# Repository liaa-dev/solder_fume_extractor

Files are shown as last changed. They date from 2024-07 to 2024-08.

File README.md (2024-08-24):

# Solder Fume Extractor

A DIY solder fume extractor crafted from a simple USB office fan.

Before:
usb office fan

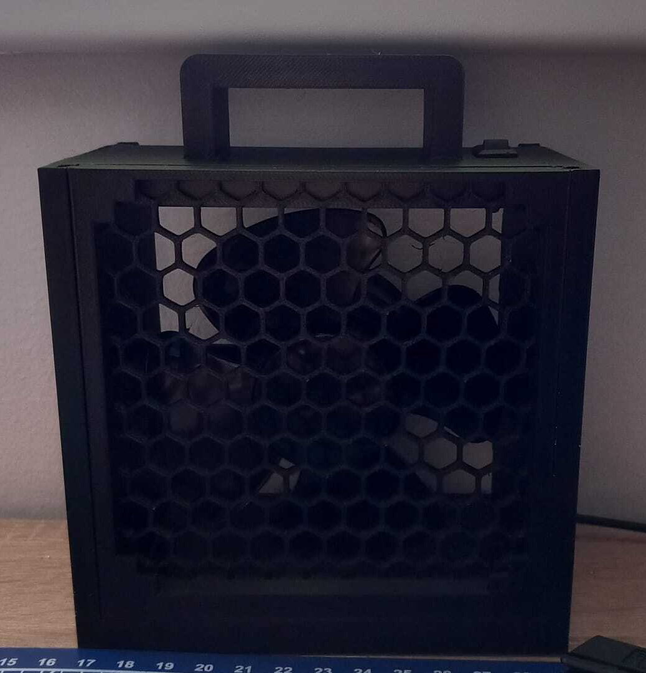
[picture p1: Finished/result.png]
result
After: 

## Description

This repository provides all the necessary files and instructions to build a solder fume extractor using a repurposed USB office fan. The 3D models have been designed in Autodesk Fusion 360 and are optimized for printing on standard 3D printers.

## Requirements

To create your own solder fume extractor, you'll need:

- **3D Printer**: A printer with a minimum bed size of 18x18x18 cm.
- **Filament**: PLA is recommended, but other materials may also be suitable.
- **USB Office Fan**: Ensure the fan has three screws on the back for secure attachment.                   
   [Example link to purchase fan](https://www.amazon.de/CSL-Ventilator-Tischventilator-Schreibtisch-Aus-Schalter/dp/B00CHI1H2S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)       
[Another example link to purchase fan](https://www.allbranded.at/p/USB-Ventilator-schwarz-ohne-Werbeanbringung/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)
- **Charcoal Filter (Front)**: Any filter up to 0.5mm thick.
- **HEPA Filter (Back)**: Any filter up to 0.5mm thick.

## Assembly Instructions

1. Download the files labeled "Filter Back," "Filter Front," and "Fume Extractor Main" from the `/finished` folder.
2. Import these files into your preferred slicer software.
3. Print the components using your 3D printer.

*Note*: Additional files such as screws and nuts are included for potential future enhancements (e.g., solder arms or adjustable arms). These components are optional and not required for the basic fume extractor assembly.

The estimated filament usage is:
- **Filter components**: 140g to 180g per filter (multiply by 2 for both filters).
- **Main part**: Approximately 260g.

## Usage Warning

**Important**: If you intend to print the screws and nuts, apply an XY Compensation of 0.1 to 0.15mm (e.g., in Bambu Slicer). This adjustment is essential to ensure proper fit and functionality of the screws and nuts.

## Contributing

Contributions are welcome! If you enhance or update this project, please use the provided screw and nut files from the `/finished` folder. This will help maintain compatibility with the existing design and avoid measurement issues.

When contributing, ensure that all relevant tests and validations are updated accordingly.

## License

This project is licensed under the MIT License. See the [LICENSE](https://pitt.libguides.com/openlicensing/MIT) file for more details.

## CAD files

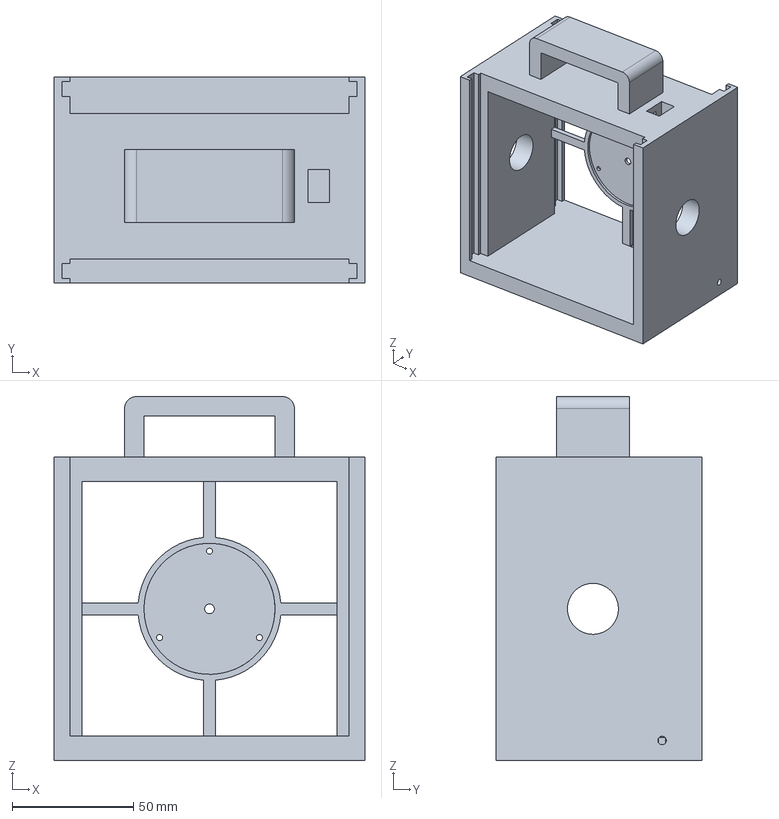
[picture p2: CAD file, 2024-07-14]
Finished/Fume Extractor Main.step
128.0 x 85.0 x 150.0 mm

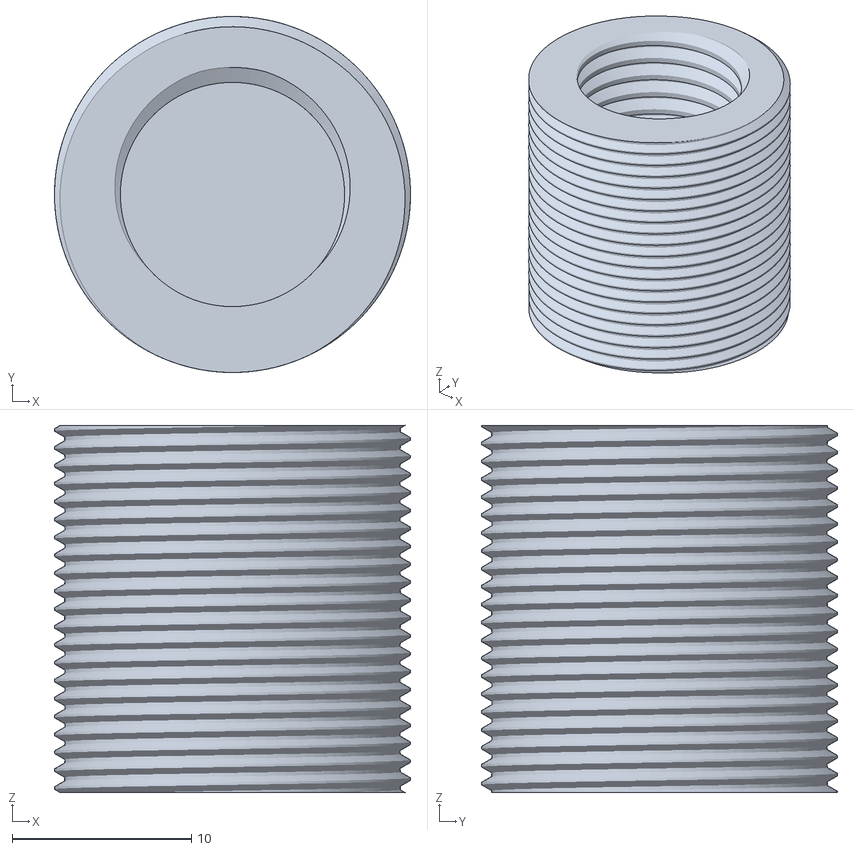
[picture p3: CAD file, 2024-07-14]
Finished/Gewinde.stl
19.9 x 19.9 x 20.5

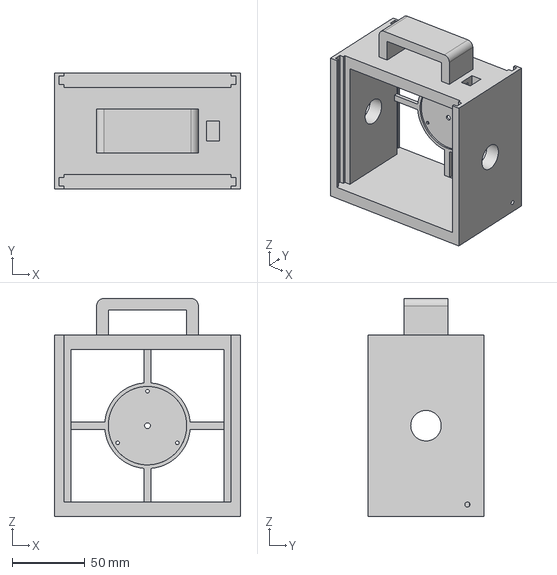
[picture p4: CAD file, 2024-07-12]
session-commits/improved.step
128.0 x 80.0 x 150.0 mm

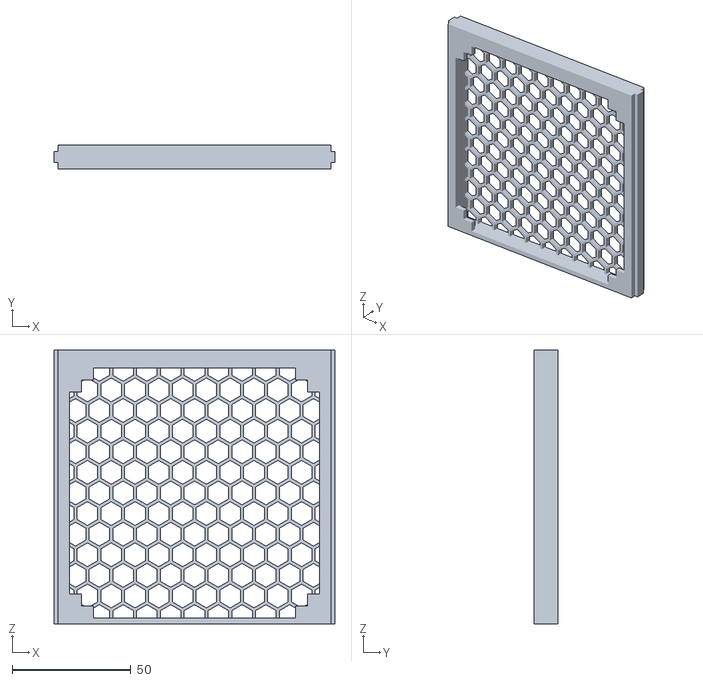
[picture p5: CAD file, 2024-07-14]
Finished/Filter Front.stl
118.1 x 10.0 x 115.0

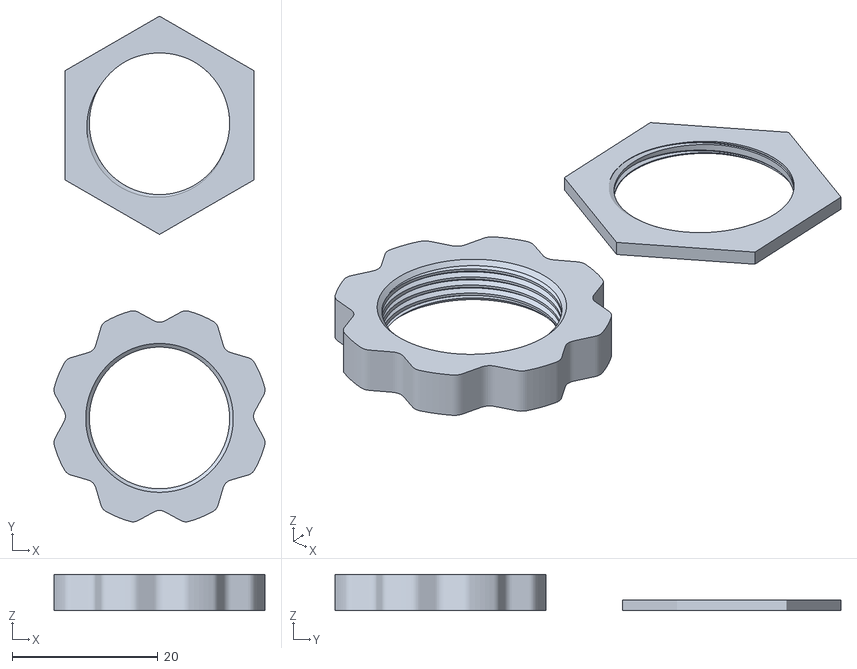
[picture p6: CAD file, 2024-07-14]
Finished/Außen Mutter.stl
29.0 x 69.5 x 5.00

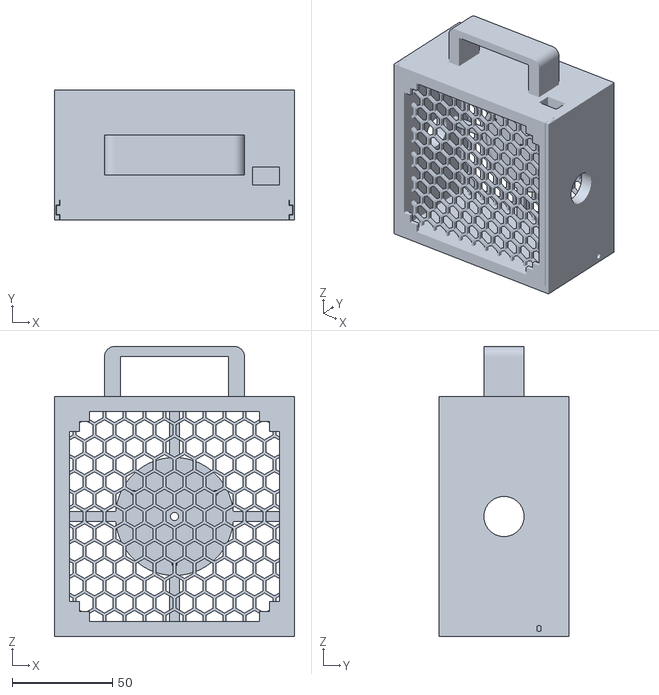
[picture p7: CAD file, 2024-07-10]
session-commits/Solder Fume Extractor v2.stl
120.0 x 65.0 x 145.0

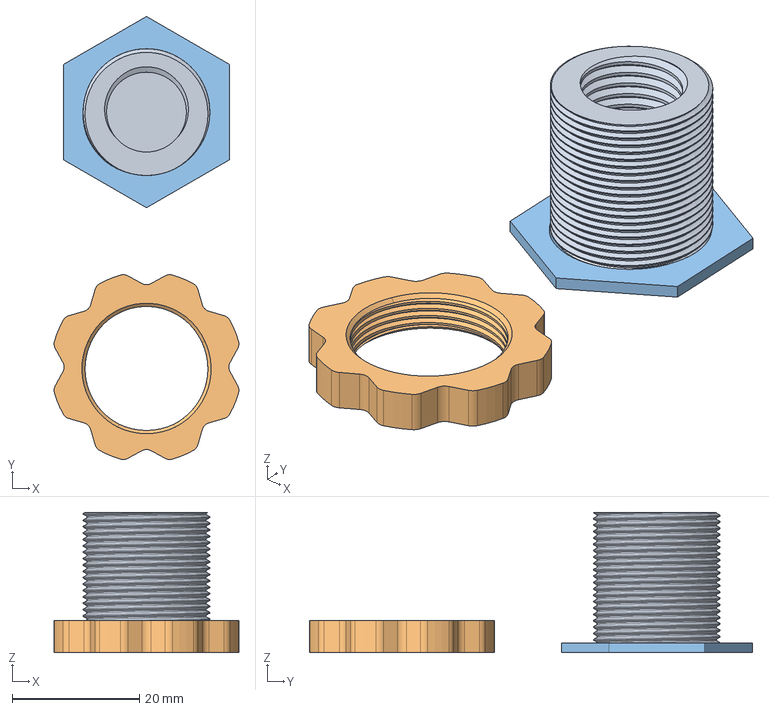
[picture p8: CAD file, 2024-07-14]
Finished/Gewinde & Muttern.step
29.0 x 69.5 x 22.0 mm

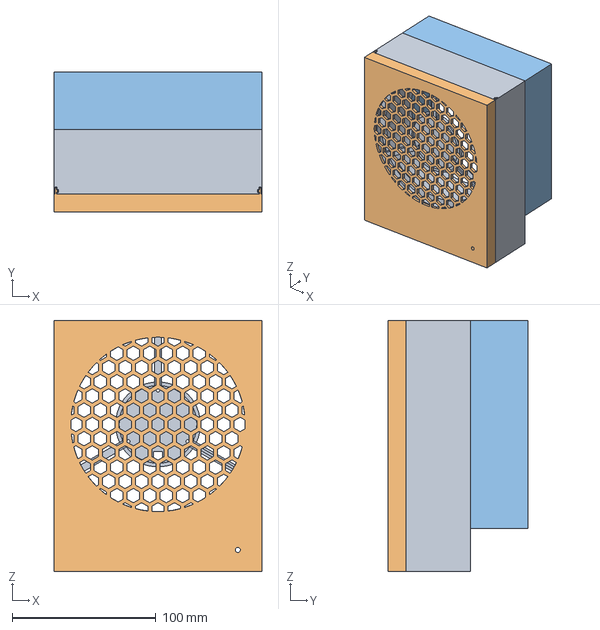
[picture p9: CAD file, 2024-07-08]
session-commits/Solder Fume Extractor v1.step
144.5 x 97.5 x 174.5 mm

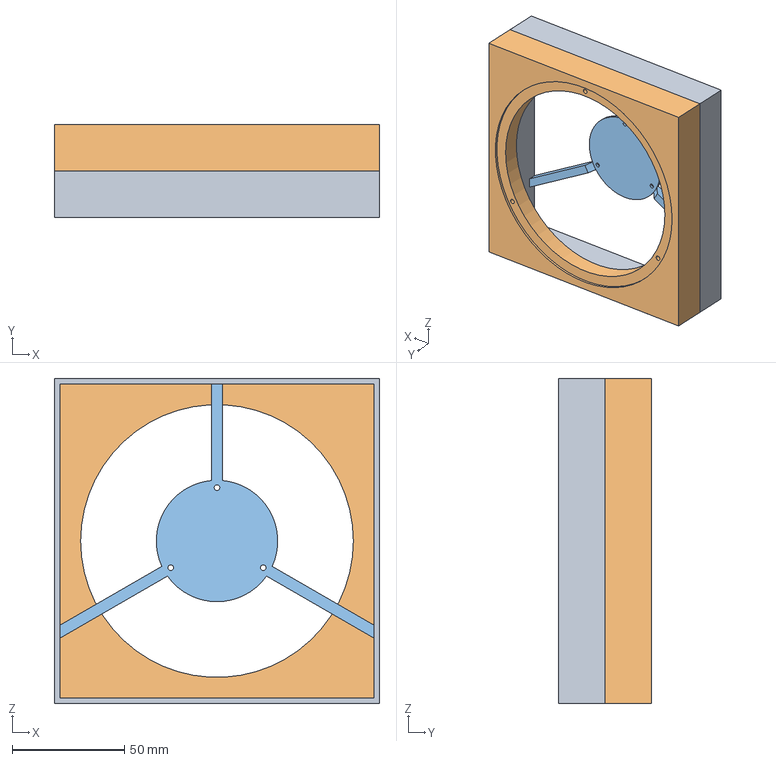
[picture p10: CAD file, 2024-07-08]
session-commits/My Solder Fume Extractor.step
144.5 x 41.5 x 144.5 mm

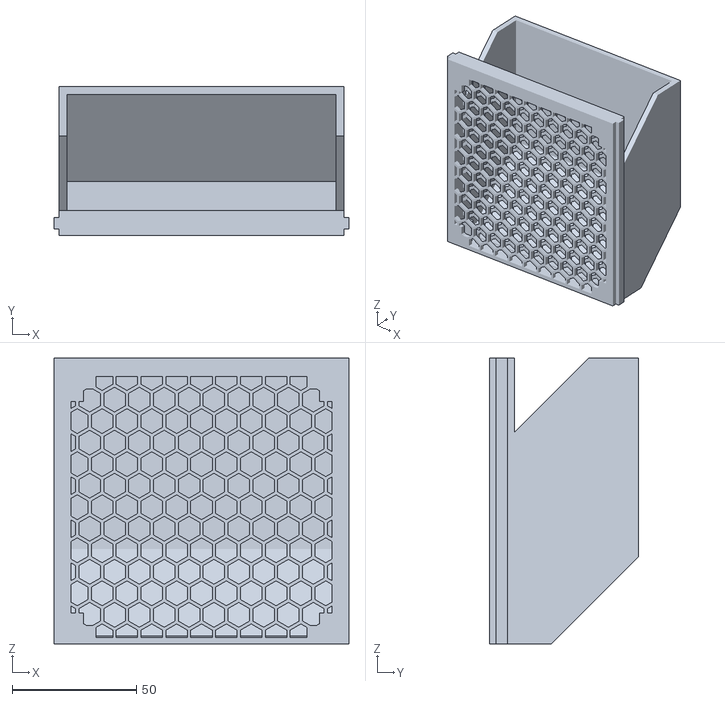
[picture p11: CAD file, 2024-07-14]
Finished/Filter Back.stl
118.7 x 60.0 x 115.0

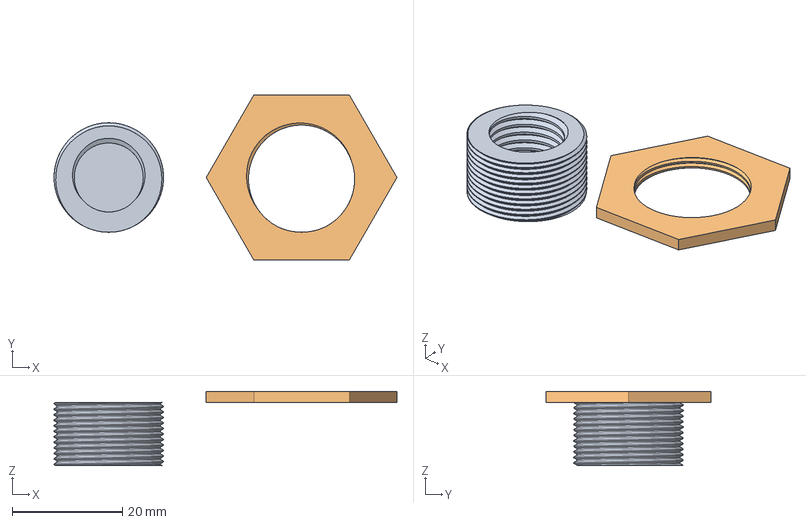
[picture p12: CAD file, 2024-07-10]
session-commits/Armscrew for Solder Fume Extractor v2.step
62.3 x 30.0 x 13.5 mm

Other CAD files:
session-commits/New Solder Fume Extractor.step
Finished/Fume Extractor Main.stl
session-commits/Armscrew for Solder Fume Extractor v2.stl
session-commits/My Solder Fume Extractor.stl
session-commits/New Solder Fume Extractor.stl
session-commits/Solder Fume Extractor v1.stl
session-commits/improved.stl

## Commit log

2024-07-08 not done yet
    [My Solder Fume Extractor.step, My Solder Fume Extractor.stl]
2024-07-08 Finished the v1 of the soldering extractor
    Maybe I will redesign it if I notice something needs to be made better but that's it for v1
    [Solder Fume Extractor v1.step, Solder Fume Extractor v1.stl]
2024-07-10 Redesign filter in back and front
    [New Solder Fume Extractor.step, New Solder Fume Extractor.stl]
2024-07-10 Solder Fume Extractor v2
    Added Soldering arm holder, 2 Filter places (one hepa, other one carbon), made it smaller
    [Solder Fume Extractor v2.step, Solder Fume Extractor v2.stl]
2024-07-10 The Screw and nut for the 2 arm holder holes
    [Armscrew for Solder Fume Extractor v2.step, Armscrew for Solder Fume Extractor v2.stl]
2024-07-12 Improved design of final v2
    Changed following bullet points:
    Need to make the slide in for the filters more loose
    need to make the handle for carrying it thicker
    need to increase strength of slide in
    need to increase thickness of whole main body
    need to add more place for the on/off switch so it doesnt collide with the fan
    need to make the cable managment tunnels for connecting from on/off switch to fan and back better and easier to set up and more place for it so my fingers can get there
    need the add more depth to the cube as the fan collides with the front filter when attaching it (about 15mm more length is needed)
    [improved.step, improved.stl]
2024-07-14 Made improvements to v3, new screws, new backfilter
    [Außen Mutter.stl, Filter Back.stl, Filter Front.stl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]
2024-08-24 Update and rename improved.step to session-commits/improved.step
    [improved.step]
2024-08-24 Rename Solder Fume Extractor v2.stl to session-commits/Solder Fume Extractor v2.stl
    [Solder Fume Extractor v2.stl]
2024-08-24 Rename Solder Fume Extractor v2.step to session-commits/Solder Fume Extractor v2.step
    [Solder Fume Extractor v2.step]
2024-08-24 Rename Solder Fume Extractor v1.stl to session-commits/Solder Fume Extractor v1.stl
    [Solder Fume Extractor v1.stl]
2024-08-24 Update and rename Solder Fume Extractor v1.step to session-commits/Solder Fume Extractor v1.step
    [Solder Fume Extractor v1.step]
2024-08-24 Rename New Solder Fume Extractor.stl to session-commits/New Solder Fume Extractor.stl
    [New Solder Fume Extractor.stl]
2024-08-24 Rename New Solder Fume Extractor.step to session-commits/New Solder Fume Extractor.step
    [New Solder Fume Extractor.step]
2024-08-24 Rename My Solder Fume Extractor.stl to session-commits/My Solder Fume Extractor.stl
    [My Solder Fume Extractor.stl]
2024-08-24 Update and rename My Solder Fume Extractor.step to session-commits/My Solder Fume Extractor.step
    [My Solder Fume Extractor.step]
2024-08-24 Update and rename Armscrew for Solder Fume Extractor v2.step to session-commits/Armscrew for Solder Fume Extractor v2.step
    [Armscrew for Solder Fume Extractor v2.step]
2024-08-24 Rename Armscrew for Solder Fume Extractor v2.stl to session-commits/Armscrew for Solder Fume Extractor v2.stl
    [Armscrew for Solder Fume Extractor v2.stl]
